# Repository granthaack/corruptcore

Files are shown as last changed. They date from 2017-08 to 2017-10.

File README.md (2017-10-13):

# Corrupt Core
## Overview

This device induces corruptions (glitches) inside of retro videogame console hardware. It is controlled with an AVR ATMEGA328p running the Arduino bootloader and using various Arduino libraries. It is designed to run off of 5V, a voltage level that can be commonly found inside of retro videogame consoles.

## Inducing a Corruption

To create a corruption, the corrupt core forces a bus line inside of the videogame console to always read as logic low. It does this by using a darlington transistor to sink the bus line to ground. This changes the data being transmitted inside the videogame console, and corrupts the game.

## User Input

A 4x4 matrix of 16 buttons are hooked up to the AVR to allow for general purpose user input. Users will be able to program each of these buttons to perform whatever kind of corruption they want.

Pinouts are also provided for 3 potentiometers to be hooked up to the analog input pins of the AVR. This enables users to create dials that can specify different levels of corruption for various groups of bus lines.

## Connecting to the Videogame Console

28 individually addressable pins are provided to the user to connect to various bus lines inside the videogame console. 

24 of these pins are addressed through a bank of 3 serial in - parallel out shift registers, and are designed for general purpose use.

4 pins are labeled as Quick Corrupt Pins. This is to address a problem with sensitive bus lines inside the videogame console. If a bus line is held low for too long, there's a possibility that it will always induce a crash. However, if a bus line can be pulled low very quickly (for only a couple of clock cycles of the game console) it can result in a much more stable and interesting corruption. These pins are hooked directly to the AVR and implement special code in order to induce a logic low pulse as fast as possible.

## Programming the Corrupt Core

The corrupt core is currently designed to hook up to an empty Arduino programmer for programming. The TX, RX, RESET, 5V, and GND lines are plugged into the appropriate pins on the programmer, and the program can be uploaded just like a regular Arduino.

I realize this is obtuse and a little wierd, and there will be a future revision of the Corrupt Core that works like an Arduino Shield. I'm building it like this as a prototype, and because it makes the corrupt core easy to integrate into the videogame console.

## Notes
Please note, I do not have any formal training in Electrical Engineering or PCB design. If my schematic or board is terrible, do not hesistate to open an issue and let me know. I'm basically figuring all of this out as I go along.

##License Info
Corrupt Core
This device and software is designed to induce real time glitches in videogame hardware
Copyright (C) 2017 Grant Haack

This program is free software: you can redistribute it and/or modify it under the terms of the GNU General Public License as published by the Free Software Foundation, either version 3 of the License, or (at your option) any later version.

This program is distributed in the hope that it will be useful, but WITHOUT ANY WARRANTY; without even the implied warranty of MERCHANTABILITY or FITNESS FOR A PARTICULAR PURPOSE.  See the GNU General Public License for more details.

You should have received a copy of the GNU General Public License along with this program.  If not, see <http://www.gnu.org/licenses/>.

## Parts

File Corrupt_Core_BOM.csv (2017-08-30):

Digi-Key Part Number | Manufacturer | Manufacturer Part Number | Customer Reference | Quantity 1 | Quantity 2 | Quantity 3 | Mfg Std Lead Time | Description | Comments | RoHS Status | Lead Free Status | REACH Status
450-1650-ND | TE CONNECTIVITY ALCOSWITCH | 1825910-6 |  | 1 | 0 | 0 | 13 Weeks | SWITCH TACTILE SPST-NO 0.05A 24V |  | RoHS Compliant | Lead free | Not Available
296-14857-1-ND | TEXAS INSTRUMENTS (VA) | SN74HC595DR |  | 4 | 0 | 0 | 9 Weeks | IC 8BIT SHIFT REG 3ST-OUT 16SOIC | Alternate Packaging Exists | RoHS Compliant | Lead free | Unaffected Jun-2016
296-15777-1-ND | TEXAS INSTRUMENTS (VA) | ULN2803ADWR |  | 4 | 0 | 0 | 15 Weeks | TRANS 8NPN DARL 50V 0.5A 18SO | Alternate Packaging Exists | RoHS Compliant | Lead free | Unaffected Jun-2016
LTC1799CS5#TRMPBFCT-ND | LINEAR TECHNOLOGY (VA) | LTC1799CS5#TRMPBF |  | 1 | 0 | 0 | 6 Weeks | IC OSC SILICON PROG TSOT23-5 | Alternate Packaging Exists | RoHS Compliant | Lead free | Unaffected Jan-2017
987-1733-ND | TT ELECTRONICS/BI | P160KNP-0QC15B50K |  | 3 | 0 | 0 | 11 Weeks | POT 50K OHM 1/5W PLASTIC LINEAR |  | RoHS Compliant | Lead free | Unaffected Jun-2016
399-1113-1-ND | KEMET (VA) | C0805C220J5GACTU |  | 2 | 0 | 0 | 15 Weeks | CAP CER 22PF 50V C0G/NP0 0805 | Alternate Packaging Exists | RoHS Compliant | Lead free | Unaffected Jun-2016
399-4925-1-ND | KEMET (VA) | C0805C106K8PACTU |  | 1 | 0 | 0 | 14 Weeks | CAP CER 10UF 10V X5R 0805 | Alternate Packaging Exists | RoHS Compliant | Lead free | Unaffected Jun-2016
P10KADCT-ND | PANASONIC ELECTRONIC COMPONENTS (VA) | ERJ-P06J103V |  | 1 | 0 | 0 | 17 Weeks | RES SMD 10K OHM 5% 1/2W 0805 | Alternate Packaging Exists | RoHS Compliant | Lead free | Unaffected Jan-2017
P150ACT-ND | PANASONIC ELECTRONIC COMPONENTS (VA) | ERJ-6GEYJ151V |  | 2 | 0 | 0 | 40 Weeks | RES SMD 150 OHM 5% 1/8W 0805 | Alternate Packaging Exists | RoHS Compliant | Lead free | Unaffected Jan-2017
160-1446-1-ND | LITE-ON INC (VA) | LTST-C191KGKT |  | 1 | 0 | 0 | 14 Weeks | LED GREEN CLEAR 0603 SMD | Alternate Packaging Exists | RoHS Compliant | Lead free | Unaffected Dec-2015
160-1647-1-ND | LITE-ON INC (VA) | LTST-C191TBKT |  | 1 | 0 | 0 | 14 Weeks | LED BLUE CLEAR 0603 SMD | Alternate Packaging Exists | RoHS Compliant | Lead free | Unaffected Dec-2015
679-2453-ND | APEM INC. | MJTP1250 |  | 16 | 0 | 0 | 15 Weeks | SWITCH TACTILE SPST-NO 0.05A 12V |  | RoHS Compliant | Lead free | Unaffected Jun-2016
445-6396-1-ND | TDK CORPORATION (VA) | MLZ2012M100WT000 |  | 1 | 0 | 0 | 10 Weeks | FIXED IND 10UH 350MA 470 MOHM | Alternate Packaging Exists | RoHS Compliant | Lead free | Unaffected Jan-2017
FMMT614CT-ND | DIODES INCORPORATED (VA) | FMMT614TA |  | 4 | 0 | 0 | 16 Weeks | TRANS NPN DARL 100V 0.5A SOT23-3 | Alternate Packaging Exists | RoHS Compliant | Lead free | Unaffected Jan-2017
887-2014-ND | TXC CORPORATION | 9B-16.000MAAE-B |  | 1 | 0 | 0 | 13 Weeks | CRYSTAL 16.0000MHZ 12PF T/H |  | RoHS Compliant | Lead free | Not Available
ED3050-5-ND | ON SHORE TECHNOLOGY INC | ED281DT |  | 1 | 0 | 0 | 10 Weeks | CONN IC DIP SOCKET 28POS TIN |  | RoHS Compliant | Lead free | Unaffected Jun-2016

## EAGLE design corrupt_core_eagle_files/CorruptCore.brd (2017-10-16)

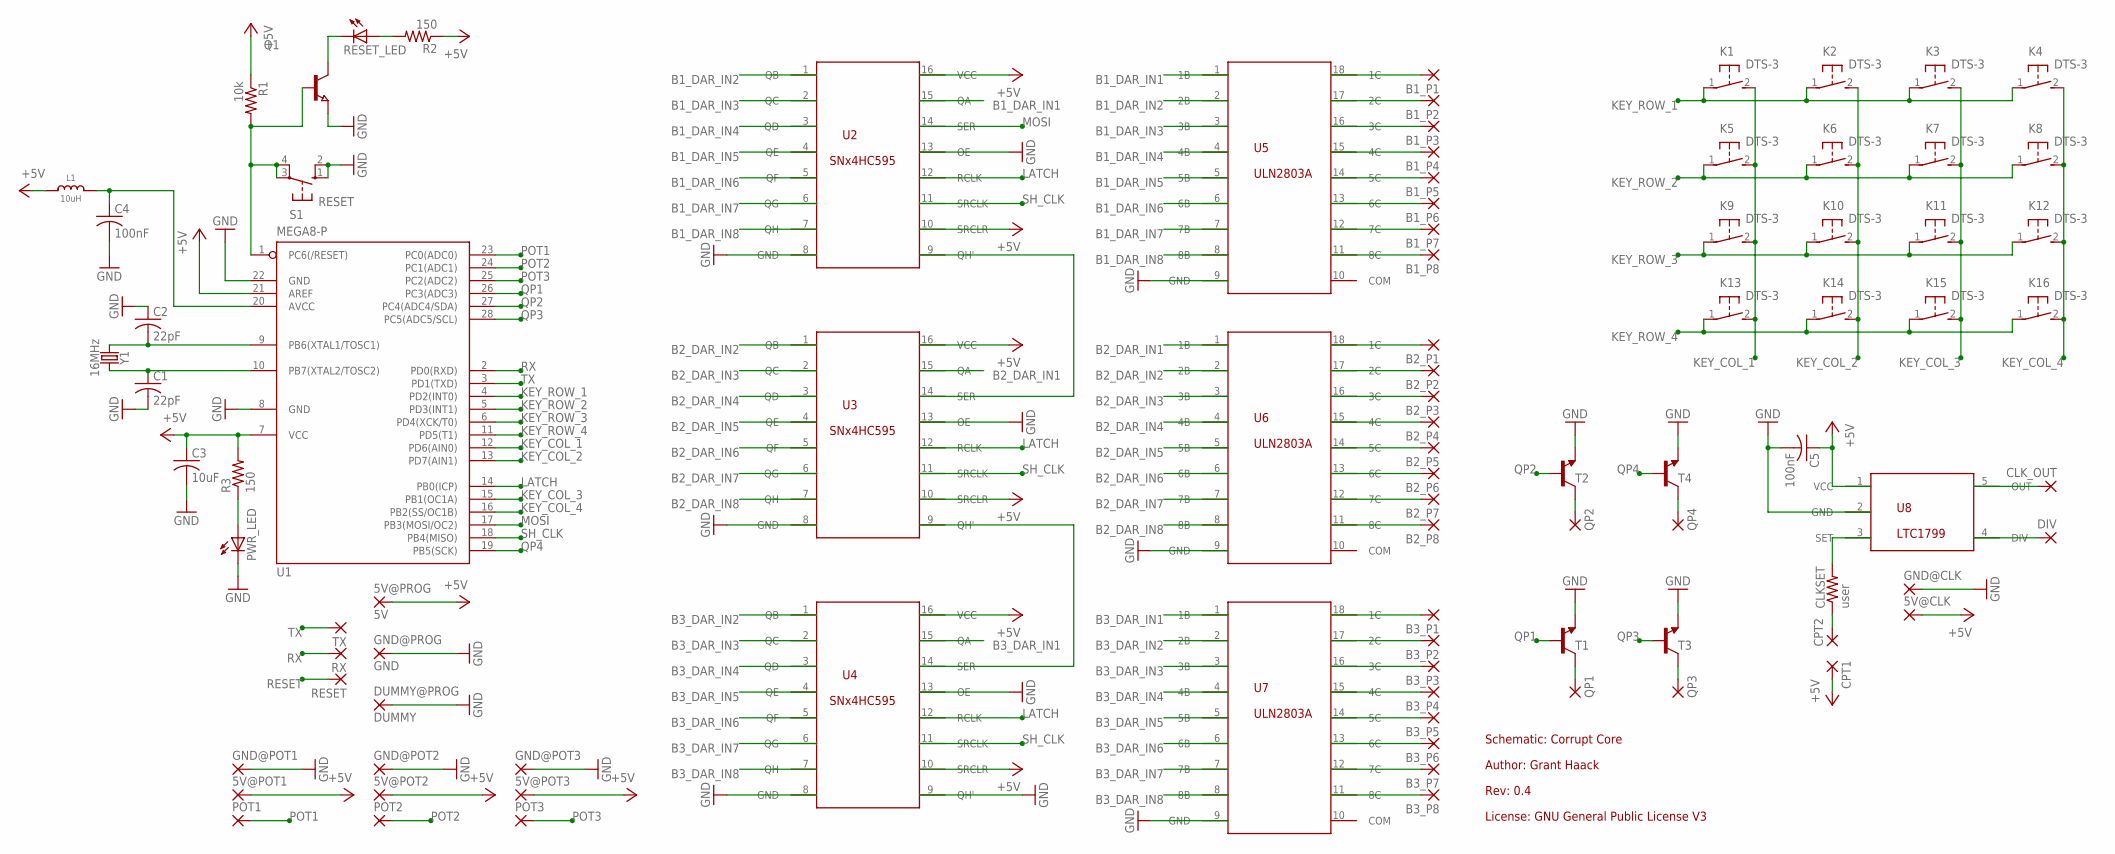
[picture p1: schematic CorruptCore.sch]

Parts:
5V@CLK, 5V@POT1, 5V@POT2, 5V@POT3: 1,6/0,8
5V@PROG: 5V; 1,6/0,8
B1_P1, B1_P2, B1_P3, B1_P4, B1_P5, B1_P6, B1_P7, B1_P8, B2_P1, B2_P2, B2_P3, B2_P4, B2_P5, B2_P6, B2_P7, B2_P8, B3_P1, B3_P2, B3_P3, B3_P4, B3_P5, B3_P6, B3_P7, B3_P8: 1,6/0,8
C1, C2: 22pF; C0805
C3: 10uF; C0805
C4, C5: 100nF; C0805
CLKSET: user; 0207/7
CLK_OUT: 1,6/0,8
CPT1, CPT2: 1,6/0,8
DIV: 1,6/0,8
DUMMY@PROG: DUMMY; 1,6/0,8
GND@CLK: 1,6/0,8
GND@POT1, GND@POT2, GND@POT3: 1,6/0,8
GND@PROG: GND; 1,6/0,8
K1, K2, K3, K4, K5, K6, K7, K8, K9, K10, K11, K12, K13, K14, K15, K16: DTS-3
L1: 10uH; MICROBUILDER__0805
POT1, POT2, POT3: 1,6/0,8
PWR_LED: LEDCHIPLED_0603; CHIPLED_0603
Q1: NPN-TRANSISTOR_SOT23; SOT23
QP1, QP2, QP3, QP4: 1,6/0,8
R1: 10k; R0805
R2, R3: 150; R0805
RESET: 1,6/0,8
RESET_LED: LEDCHIPLED_0603; CHIPLED_0603
RX: 1,6/0,8
S1: RESET; B3F-10XX
T1, T2, T3, T4: TRANS_NPN-MMBTA42; SOT23-3
TX: 1,6/0,8
U1: MEGA8-P; DIL28-3
U2, U3, U4: SNX4HC595SOIC16; SOIC16N
U5, U6, U7: ULN2803ASOIC18; SO18L
U8: LTC1799; SOT23-5L
Y1: 16MHz; HC49US

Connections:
+5V: 5V@CLK.1, 5V@POT1.1, 5V@POT2.1, 5V@POT3.1, 5V@PROG.1, C3.1, C5.1, CPT1.1, L1.1, R1.1, R2.1, R3.2, U1.7 (VCC), U1.21 (AREF), U2.10 (SRCLR), U2.16 (VCC), U3.10 (SRCLR), U3.16 (VCC), U4.10 (SRCLR), U4.16 (VCC), U8.1 (VCC)
B1_DAR_IN1: U2.15 (QA), U5.1 (1B)
B1_DAR_IN2: U2.1 (QB), U5.2 (2B)
B1_DAR_IN3: U2.2 (QC), U5.3 (3B)
B1_DAR_IN4: U2.3 (QD), U5.4 (4B)
B1_DAR_IN5: U2.4 (QE), U5.5 (5B)
B1_DAR_IN6: U2.5 (QF), U5.6 (6B)
B1_DAR_IN7: U2.6 (QG), U5.7 (7B)
B1_DAR_IN8: U2.7 (QH), U5.8 (8B)
B1_P1: B1_P1.1, U5.18 (1C)
B1_P2: B1_P2.1, U5.17 (2C)
B1_P3: B1_P3.1, U5.16 (3C)
B1_P4: B1_P4.1, U5.15 (4C)
B1_P5: B1_P5.1, U5.14 (5C)
B1_P6: B1_P6.1, U5.13 (6C)
B1_P7: B1_P7.1, U5.12 (7C)
B1_P8: B1_P8.1, U5.11 (8C)
B2_DAR_IN1: U3.15 (QA), U6.1 (1B)
B2_DAR_IN2: U3.1 (QB), U6.2 (2B)
B2_DAR_IN3: U3.2 (QC), U6.3 (3B)
B2_DAR_IN4: U3.3 (QD), U6.4 (4B)
B2_DAR_IN5: U3.4 (QE), U6.5 (5B)
B2_DAR_IN6: U3.5 (QF), U6.6 (6B)
B2_DAR_IN7: U3.6 (QG), U6.7 (7B)
B2_DAR_IN8: U3.7 (QH), U6.8 (8B)
B2_P1: B2_P1.1, U6.18 (1C)
B2_P2: B2_P2.1, U6.17 (2C)
B2_P3: B2_P3.1, U6.16 (3C)
B2_P4: B2_P4.1, U6.15 (4C)
B2_P5: B2_P5.1, U6.14 (5C)
B2_P6: B2_P6.1, U6.13 (6C)
B2_P7: B2_P7.1, U6.12 (7C)
B2_P8: B2_P8.1, U6.11 (8C)
B3_DAR_IN1: U4.15 (QA), U7.1 (1B)
B3_DAR_IN2: U4.1 (QB), U7.2 (2B)
B3_DAR_IN3: U4.2 (QC), U7.3 (3B)
B3_DAR_IN4: U4.3 (QD), U7.4 (4B)
B3_DAR_IN5: U4.4 (QE), U7.5 (5B)
B3_DAR_IN6: U4.5 (QF), U7.6 (6B)
B3_DAR_IN7: U4.6 (QG), U7.7 (7B)
B3_DAR_IN8: U4.7 (QH), U7.8 (8B)
B3_P1: B3_P1.1, U7.18 (1C)
B3_P2: B3_P2.1, U7.17 (2C)
B3_P3: B3_P3.1, U7.16 (3C)
B3_P4: B3_P4.1, U7.15 (4C)
B3_P5: B3_P5.1, U7.14 (5C)
B3_P6: B3_P6.1, U7.13 (6C)
B3_P7: B3_P7.1, U7.12 (7C)
B3_P8: B3_P8.1, U7.11 (8C)
GND: C1.2, C2.1, C3.2, C4.2, C5.2, DUMMY@PROG.1, GND@CLK.1, GND@POT1.1, GND@POT2.1, GND@POT3.1, GND@PROG.1, PWR_LED.C, Q1.2 (E), S1.1 (S), S1.2 (S1), T1.2 (E), T2.2 (E), T3.2 (E), T4.2 (E), U1.8 (GND), U1.22 (GND), U2.8 (GND), U2.13 (OE), U3.8 (GND), U3.13 (OE), U4.8 (GND), U4.9 (QH'), U4.13 (OE), U5.9 (GND), U6.9 (GND), U7.9 (GND), U8.2 (GND)
KEY_COL_1: K1.2, K5.2, K9.2, K13.2, U1.12 (PD6(AIN0))
KEY_COL_2: K2.2, K6.2, K10.2, K14.2, U1.13 (PD7(AIN1))
KEY_COL_3: K3.2, K7.2, K11.2, K15.2, U1.15 (PB1(OC1A))
KEY_COL_4: K4.2, K8.2, K12.2, K16.2, U1.16 (PB2(SS/OC1B))
KEY_ROW_1: K1.1, K2.1, K3.1, K4.1, U1.4 (PD2(INT0))
KEY_ROW_2: K5.1, K6.1, K7.1, K8.1, U1.5 (PD3(INT1))
KEY_ROW_3: K9.1, K10.1, K11.1, K12.1, U1.6 (PD4(XCK/T0))
KEY_ROW_4: K13.1, K14.1, K15.1, K16.1, U1.11 (PD5(T1))
LATCH: U1.14 (PB0(ICP)), U2.12 (RCLK), U3.12 (RCLK), U4.12 (RCLK)
MOSI: U1.17 (PB3(MOSI/OC2)), U2.14 (SER)
unnamed: U2.9 (QH'), U3.14 (SER)
unnamed: U3.9 (QH'), U4.14 (SER)
unnamed: C2.2, U1.9 (PB6(XTAL1/TOSC1)), Y1.1
unnamed: C1.1, U1.10 (PB7(XTAL2/TOSC2)), Y1.2
unnamed: CLK_OUT.1, U8.5 (OUT)
unnamed: R2.2, RESET_LED.A
unnamed: PWR_LED.A, R3.1
unnamed: QP1.1, T1.3 (C)
unnamed: C4.1, L1.2, U1.20 (AVCC)
unnamed: QP2.1, T2.3 (C)
unnamed: QP3.1, T3.3 (C)
unnamed: QP4.1, T4.3 (C)
unnamed: DIV.1, U8.4 (DIV)
unnamed: CLKSET.1, CPT2.1
unnamed: CLKSET.2, U8.3 (SET)
unnamed: Q1.3 (C), RESET_LED.C
POT1: POT1.1, U1.23 (PC0(ADC0))
POT2: POT2.1, U1.24 (PC1(ADC1))
POT3: POT3.1, U1.25 (PC2(ADC2))
QP1: T1.1 (B), U1.26 (PC3(ADC3))
QP2: T2.1 (B), U1.27 (PC4(ADC4/SDA))
QP3: T3.1 (B), U1.28 (PC5(ADC5/SCL))
QP4: T4.1 (B), U1.19 (PB5(SCK))
RESET: Q1.1 (B), R1.2, RESET.1, S1.3, S1.4 (P1), U1.1 (PC6(/RESET))
RX: RX.1, U1.2 (PD0(RXD))
SH_CLK: U1.18 (PB4(MISO)), U2.11 (SRCLK), U3.11 (SRCLK), U4.11 (SRCLK)
TX: TX.1, U1.3 (PD1(TXD))

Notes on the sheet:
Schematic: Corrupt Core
Author: Grant Haack
Rev: 0.4
License: GNU General Public License V3

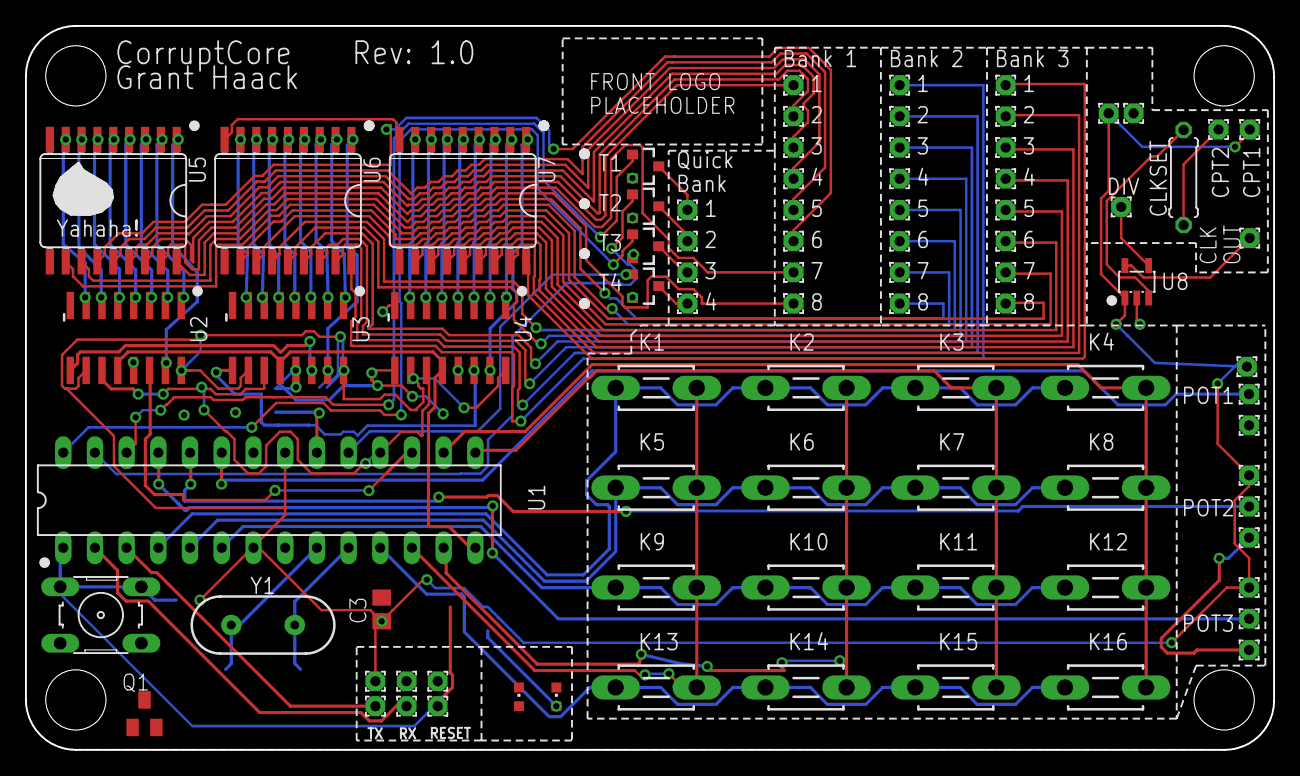
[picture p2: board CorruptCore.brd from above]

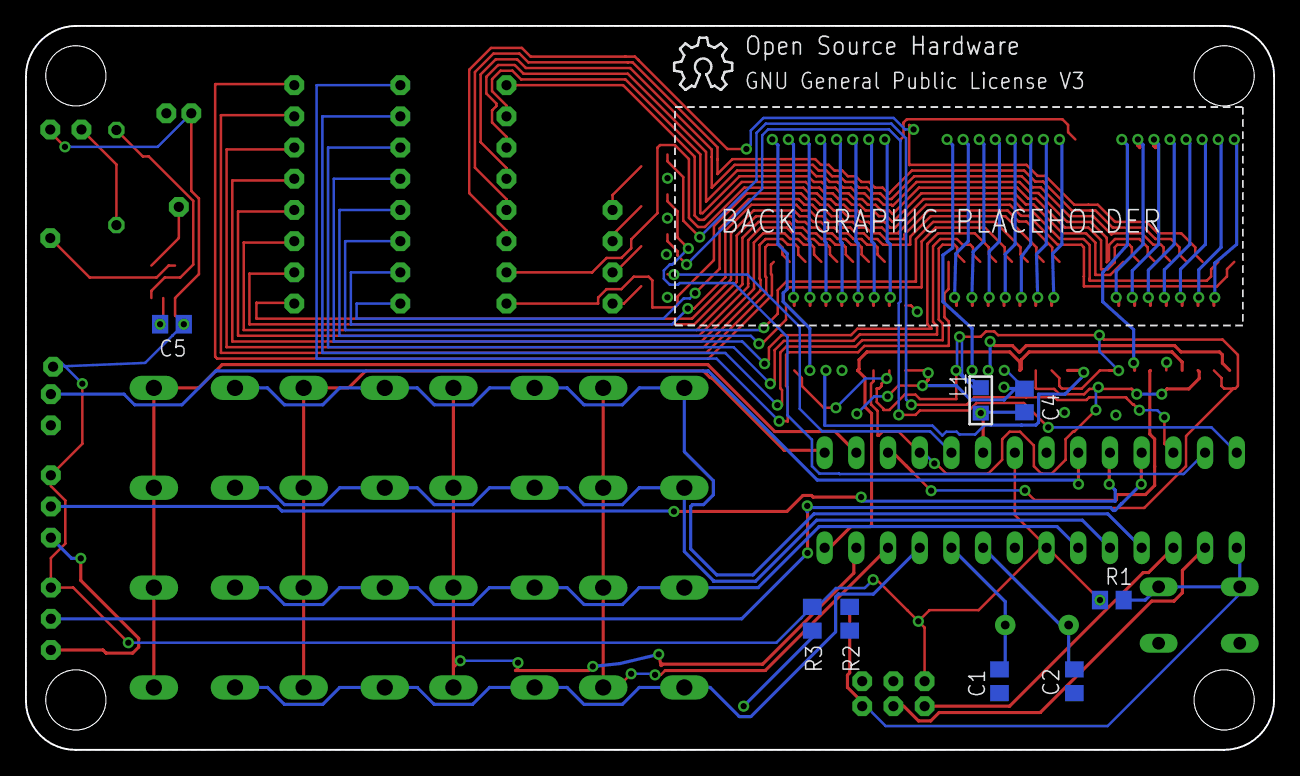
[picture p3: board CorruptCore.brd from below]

Board: 2 copper layers, 100.0 x 58.0 mm, 92 parts (8 on the bottom side), 87 nets.

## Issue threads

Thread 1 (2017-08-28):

Button matrix is all wrong

granthaack, 2017-08-28:
I don't know why I wired it like this. The whole thing is shorted together.

granthaack, 2017-08-30:
I fixed this ages ago and forgot to close it. I'm a mess.

Closed 2017-08-30.

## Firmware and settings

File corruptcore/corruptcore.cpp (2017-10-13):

/*
   corruptcore.h - Library for communicating with the CorruptCore hardware corrupter.
   Created by Grant Haack, October 12, 2017.
   Released under GNU GPL V3
*/

#include "corruptcore.h"
#include "Arduino.h"

Corrupt::Corrupt()
{
  pinMode(latch_pin, OUTPUT);
  pinMode(data_pin, OUTPUT);  
  pinMode(clock_pin, OUTPUT);
  _bank1 = 0;
  _bank2 = 0;
  _bank3 = 0;
}


void Corrupt::set_corrupt_pin(int pin, int bank, bool state)
{
  pin -= 1;
  if(state)
  {
    if(bank == 1)
    {
      _bank1 = _bank1 | (1<<pin);
    }
    if(bank == 2)
    {
      _bank2 = _bank2 | (1<<pin);
    }
    if(bank == 3)
    {
      _bank3 = _bank3 | (1<<pin);
    }
    else
    {
      return;
    }
  }
  else
  {
    if(bank == 1)
    {
      _bank1 = _bank1 & ~(1<<pin);
    }
    if(bank == 2)
    {
      _bank2 = _bank2 & ~(1<<pin);
    }
    if(bank == 3)
    {
      _bank3 = _bank3 & ~(1<<pin);
    }
    else
    {
      return;
    }
  }
  
}

void Corrupt::write_corrupt_pin() {
  digitalWrite(latch_pin, LOW);
  
  shiftOut(data_pin, clock_pin, MSBFIRST, _bank3);
  shiftOut(data_pin, clock_pin, MSBFIRST, _bank2);
  shiftOut(data_pin, clock_pin, MSBFIRST, _bank1);
  
  digitalWrite(latch_pin, HIGH);

}

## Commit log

2017-08-30 -fixed license
    [CorruptCore.brd, CorruptCore.sch]
2017-08-30 -updated the BOM because I forgot a part -moved the shitty meme
    [Corrupt_Core_BOM.csv]
2017-08-30 -whoops forgot to save
    [CorruptCore.brd]
2017-08-31 -added pin numbers for quick corrupt pins
    [CorruptCore.brd, CorruptCore.sch]
2017-09-04 -routed everything
    [CorruptCore.sch]
2017-09-08 apparently I never pushed this
    [CorruptCore.brd]
2017-10-05 -I was a dummy and wired up the RESET status LED wrong, causing a voltage drop that held the RESET line low no matter what. I fixed it so it just uses a transistor to control the RESET LED.
    [CorruptCore.brd, CorruptCore.sch]
2017-10-13 -added arduino code -updated license
2017-10-16 -added more functions to the Corrupt Core arduino code -I'm the master at vague commit logs
    [CorruptCore.brd]

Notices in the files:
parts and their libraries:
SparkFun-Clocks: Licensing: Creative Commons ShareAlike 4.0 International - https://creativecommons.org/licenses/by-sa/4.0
